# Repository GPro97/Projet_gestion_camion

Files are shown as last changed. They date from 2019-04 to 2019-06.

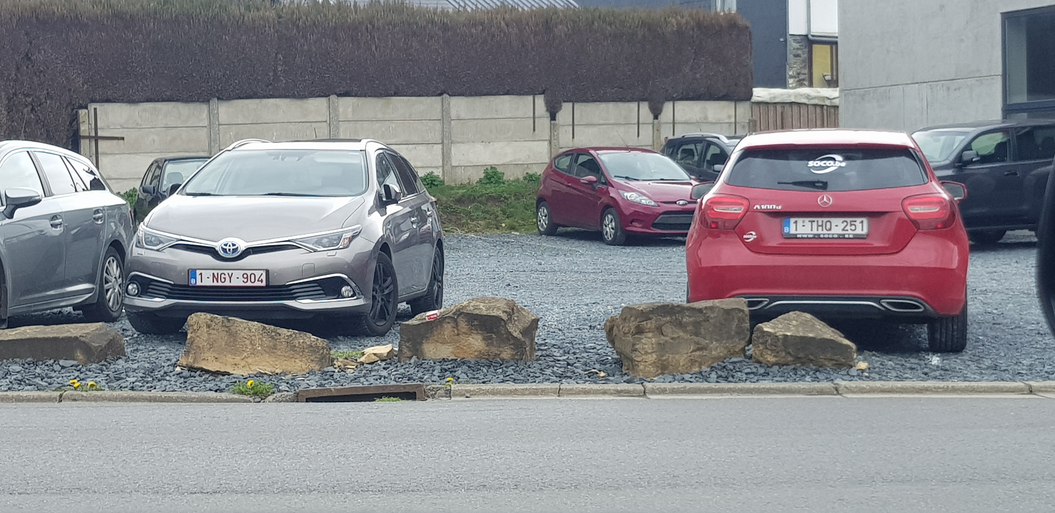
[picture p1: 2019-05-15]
images/test/img30.jpg

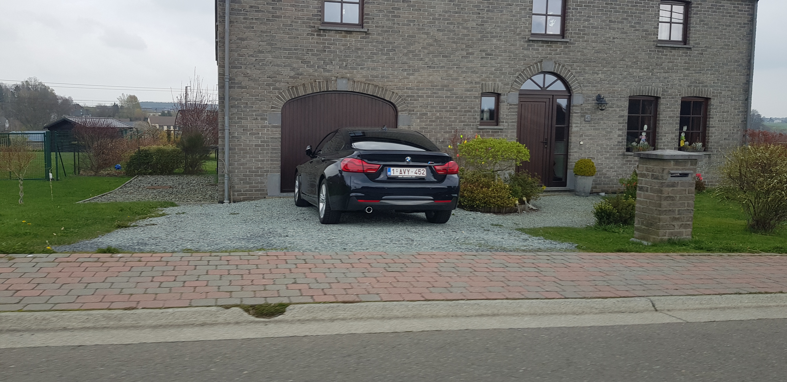
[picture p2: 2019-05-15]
images/test/img20.jpg

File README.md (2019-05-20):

# Projet_gestion_camion

## Utilisation
1. Raccorder l'alimentation du raspberry et raccorder les périphériques souvent: écran, clavier et souris
2. Vérifier que la caméra et l'écran LCD sont bien inséré dans les trous mis à disposition
3. Une fois le raspberry allumé, rendez-vous dans l'invite de commande et accédez au répertoire "tensorflow1/models/object_detection"
4. Activer le programme "python3 Object_detection_picamera_4.1.py"
5. Attendez 30 secondes pour le chargement jusqu'à ce que l'on voit à travers la caméra
6. Placez une plaque d'immatriculation devant et voyez le résultat

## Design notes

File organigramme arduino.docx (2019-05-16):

Vérifier qu’il n’y a plus de plaque et attendre en haut x secondes, puis modifié le message de l’écran

Allumage du LCD

On était l’écran, la led et on arrête les mouvements de la barrière

Démarrage programme et led pin 13 allumé

Est-ce qu’il y a une détection de plaque de plus de 1 secondes ?

Allumage du clignotement de la led rouge

Enclencher la montée de la barrière de 1 degré

Oui

Non

Est-t-elle arrivée en haut ?

Oui

Est-ce qu’on a attendu x secondes ?

Non

Enclencher la descente de la barrière de 1 degré

Oui

Est-t-elle arrivée en bas ?

Non

Oui

Non

Fin du setup

Allumage et initialisation du programme

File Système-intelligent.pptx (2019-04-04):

## Système intelligent

Reconnaissance de plaques d’immatriculation
Jérémy Denis et Geoffrey Kraus

## Description du projet

- Raspberry

- Arduino

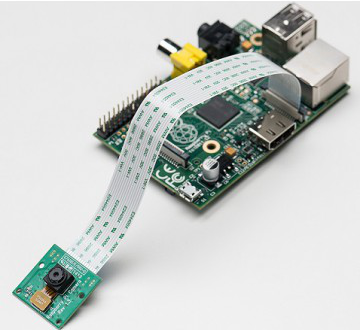
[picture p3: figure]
RÃ©sultat de recherche d'images pour "camera raspberry"

Communication

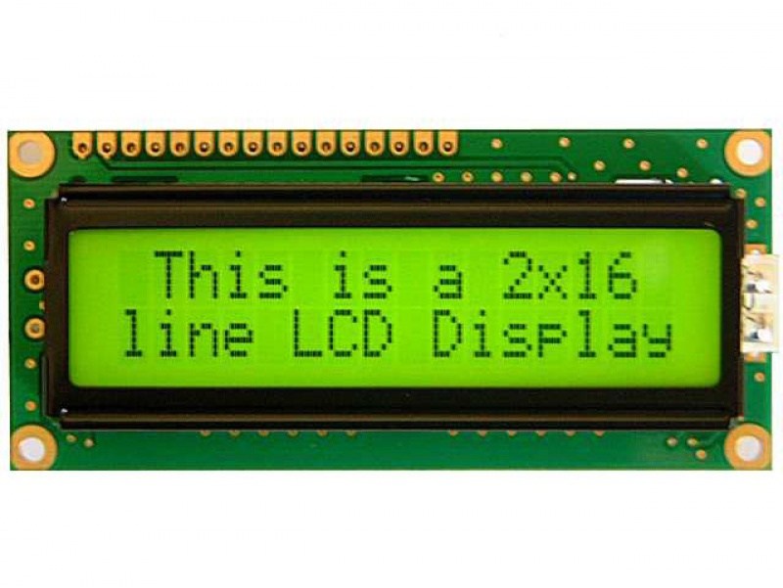
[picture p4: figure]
RÃ©sultat de recherche d'images pour "lcd"
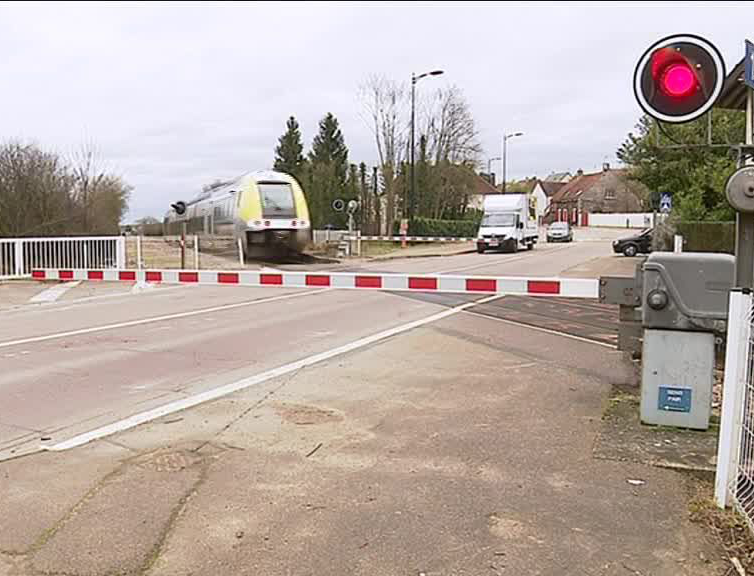
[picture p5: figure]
RÃ©sultat de recherche d'images pour "barriÃ¨re passage a niveau"
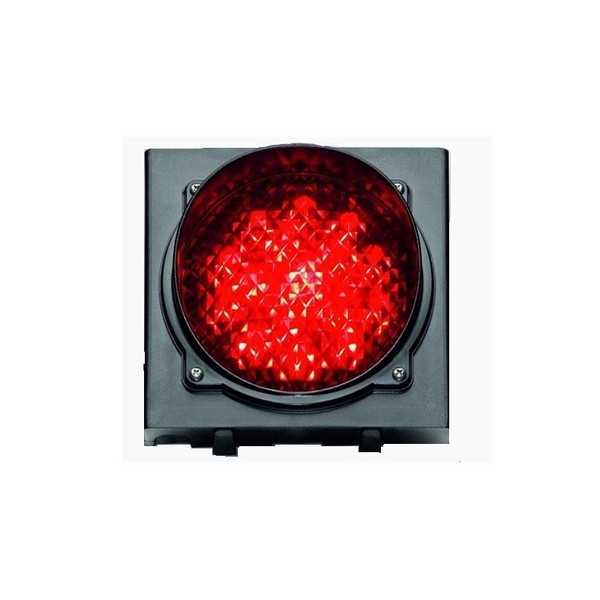
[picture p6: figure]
RÃ©sultat de recherche d'images pour "feu rouge"
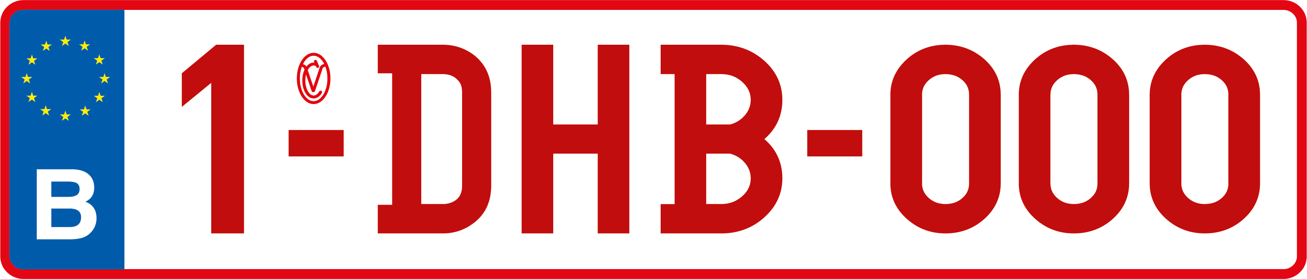
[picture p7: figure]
RÃ©sultat de recherche d'images pour "plaque d'immatriculation belge"

- Détection de plaques d’immatriculation belges

- Affichage de la plaque sur un LCD
- Gestion de l’ouverture d’une barrière lors de la détection d’une plaque
- Clignotement d’un feu lumineux lors de l’activation de la barrière

## Description du matériel nécessaire

Nous disposons de pratiquement tout le matériel nécessaire :
Arduino
LCD du kit Arduino
Raspberry Pi 3
Camera du kit Raspberry Pi 3
Led pour représenter le feu lumineux
Potentiomètre (kit Arduino) pour contrôler le clignotement de la LED
Servomoteur (kit Arduino) pour activer la barrière
Divers câbles et équipements esthétiques
Matériel manquant : barrière (imprimée en 3D ou maquette à fixer au servomoteur)

## Timeline et répartition des charges

Algorithme de reconnaissance plaque d’immatriculation

Programme de gestion de barrière et du LCD, suivi de la modélisation pratique de la barrière.

Modélisation des mises en places pratique du projet

Geoffrey

Jérémy

01/03 – 10/04

Geoffrey

47 days

Geoffrey
Jérémy

01/03 - 18/03

19/03 - 10/04

Communication entre Arduino et Raspberry

Réalisation pratique

Jérémy

10/04 – 25/04

23/04 - 03/05

Algorithme de reconnaissance des numéros écris sur la plaque

Pâques

Geoffrey

25/04 – 15/05

Feb

Mar

Apr

Mai

June

01/03/2019

15/05/2019

## Etat de l’art de l’existant

- Contrôle d’accès par lecture de plaques d’immatriculation (ALPR)
Ce système permet d’autoriser l’accès à un parking par lecture des plaques d’immatriculation. Il s’appuie sur une caméra IP associée à une carte Raspberry Pi et le logiciel de reconnaissance de plaques openALPR.
http://www.rgot.org/controle-dacces-par-lecture-de-plaques-dimmatriculation-alpr/
https://www.youtube.com/watch?v=sRnFKqWCVBM

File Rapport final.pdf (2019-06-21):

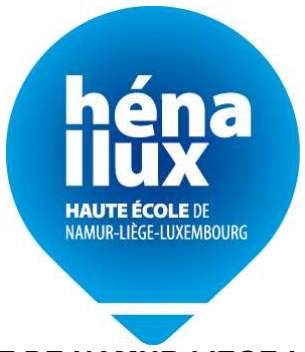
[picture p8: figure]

HAUTE ECOLE DE NAMUR-LIEGE-LUXEMBOURG

## DEPARTEMENT INGENIEUR INDUSTRIEL PIERRARD - VIRTON

### SYSTEMES INTELLIGENTS : RECONNAISSANCE D’UNE PLAQUE D’IMMATRICULATION ET CONTROLE D’UNE BARRIERE D’ENTREE

Professeurs : LIBERATORE C. et SLAMA R.

DENIS Jérémy
Année Académique | KRAUS Geoffrey
2018 – 2019 | M1A

2

## Table des matières

3

## Table des figures :

Figure 1.1 - Schéma d'illustration du projet | 4
Figure 4.1 - Schéma de câblage de l'arduino | 7
Figure 4.2 - Micro servomoteur [1] | 8
Figure 4.3 - Graphe temporel des impulsions PWM [2] | 8
Figure 4.4 - Structure du code arduino | 9
Figure 4.5 - Ordinogramme du code arduino | 10
Figure 4.6 - Barrière | 11
Figure 4.7 - Supports du servomoteur | 11
Figure 5.1 - Test de TensorFlow sur le Raspberry | 13
Figure 5.2 - Test de Protobuf sur le Raspberry | 15
Figure 5.3 - Premier test sur Raspberry | 16
Figure 5.4 - Exemple de photo prise pour l'entrainement | 17
Figure 5.5 - Logiciel LabelImg | 17
Figure 5.6 - Abandon du processus d'entrainement sur Raspberry | 20
Figure 5.7 - Fin de l'apprentissage du modèle sur Lubuntu | 20
Figure 5.8 - Modèle entrainé utilisé sur Lubuntu | 21
Figure 5.9 - Test final de la détection de plaque | 22
Figure 5.10 - Resultat final | Erreur ! Signet non défini.

## Table des tableaux :

Tableau 2.1 - Liste des composants du projet | 5

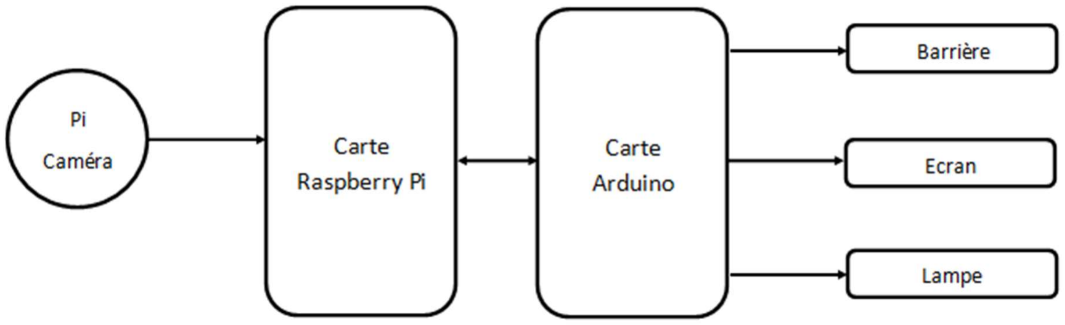
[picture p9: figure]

4

## 1. Introduction :

Dans le cadre du projet du cours de microcontrôleur et système intelligent, nous avons décidé de créer un système d’ouverture de barrière à la détection d’une plaque d’immatriculation d’un véhicule. Ce projet se divise donc en deux grandes parties : Raspberry et Arduino.
En effet, toute la partie commande de la barrière avec un écran et une lampe sera gérée par l’Arduino qui est un microcontrôleur. Et toute la partie reconnaissance de plaque est gérée par le Raspberry avec sa caméra pi.
Chaque partie sera réalisée séparément pour ensuite réaliser une communication entre les deux systèmes par le biais de un ou plusieurs câbles.

Figure 1.1 - Schéma d'illustration du projet

5

## 2. Tableau des composants

Tableau 2.1 - Liste des composants du projet
Dans le tableau 2-1, on retrouve tous les composants nécessaires au projet. En effet, on prenant la partie Arduino, on retrouve le microcontrôleur avec le LCD et le servomoteur ainsi deux potentiomètres. Un pour la luminosité du LCD et un pour une entrée analogique. Ensuite on retrouve la led rouge qui clignotera ainsi que les résistances pour protéger les potentiomètres et les leds.
Ensuite, on retrouve le raspberry avec la caméra, puis les différents fils de connections pour l’arduino ainsi qu’entre l’arduino et la raspberry. Et finalement, on retrouve le matériel nécessaire à la réalisation pratique.
En ce qui concerne l’impression 3D, on prend, ici, seulement le prix de la bobine en compte (soit 35 € du kg). Mais il faudrait également prendre en compte l’amortissement de la machine ainsi que sa consommation électrique. Données que nous ne possédons pas.
Arduino Uno | | 20,75 € | 1 | 20,75 € | Digi-Key | A000066 | [3] | Fourni par l'école
LCD | | 7,57 € | 1 | 7,57 € | Amazon | DLM-B00XOYIXI0 | [4] | Fourni par l'école
Servomoteur | | 4,75 € | 1 | 4,75 € | KAPshop | / | [5] | Fourni par l'école
Potentiomètre 10K | | 0,25 € | 2 | 0,50 € | Gotronic | 04601 | [6] | Fourni par l'école
Led rouge | | 0,15 € | 2 | 0,30 € | Gotronic | 03030 | [7] | Fourni par l'école

Résistance 220ohms
Pack de 10 | | 0,26 € | 1 | 0,26 € | RS Components | 135-500 | [8] | Fourni par l'école
Sous-total | 33,73 € Raspberry Pi 3 B+ | 63,70 € | 1 | 63,70 € | RS Components | 174-7510 | [9] | Fourni par l'école
Pi caméra V2 | | 23,09 € | 1 | | RS Components | 913-2664 | [10] | Fourni par l'école
Sous-total | 86,79 € Câble mâle-mâle | 2,41 € | 1 | 2,41 € | RS Components | 791-6463 | [11] | Fourni par l'école
Câble mâle-femelle | 2,41 € | 2 | 4,82 € | RS Components | 791-6454 | [12] | Fourni par l'école
Jumper Cable Kit Fil | 2,50 € | 1 | 2,50 € | Amazon | 14731 | [13] | Fourni par l'école
Sous-total | 7,32 € Bois | 20 € | / | / | Récupération | / | / | /
Impression 3D | | ( €/g ) | ( m ) | ( g ) | Nombre d'essai | Prix total
Barrière | 0,035 | 0,8 | 6 | 2 | 0,420 € | Fourni par l'école
Support haut du servo | 0,035 | 0,49 | 3 | 1 | 0,105 € | Fourni par l'école
Support bas du servo | 0,035 | 1,2 | 8 | 1 | 0,280 € | Fourni par l'école
Sous-total | 0,81 €
Total général | 128,65 € Raspberry Arduino Communication Montage pratique
Partie | Composants | Prix unit. | Qte | Prix tot. | Fournisseur | Réf site | Lien | Etat

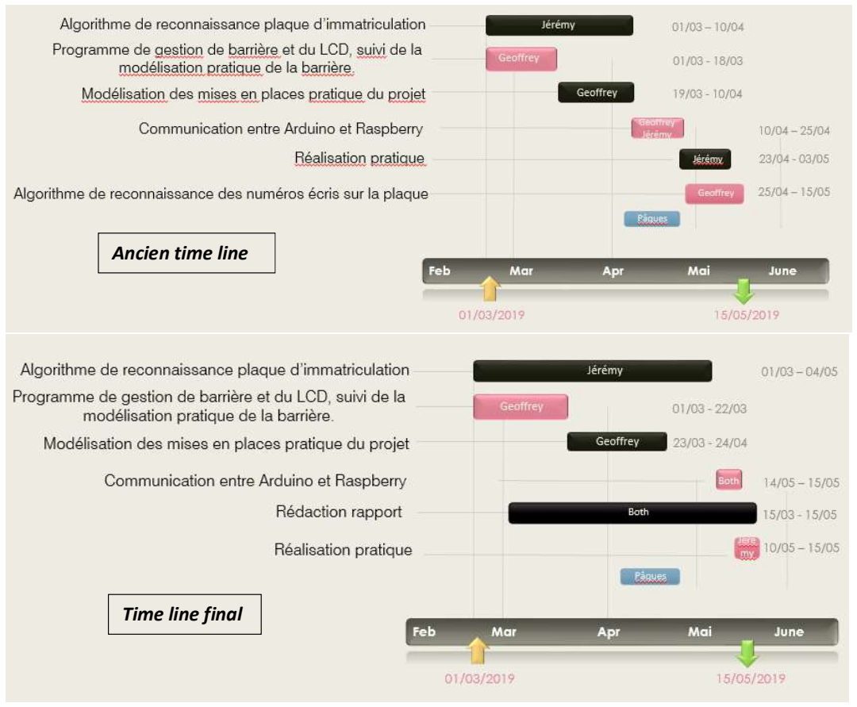
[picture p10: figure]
Ancien time line; Time line final

6

## 3. Time line final

Comme on peut remarquer, le time line a un peu bougé entre le début et la fin du projet. Et notamment parce que certaines tâches ont pris plus de temps qu’espéré. Nous avons également ajouté la partie « Rédaction du rapport » qui est tout de même une partie importante de ce projet. On peut également remarquer que la tâche « Algorithme de reconnaissance des numéros écris sur la plaque » ne fait plus partie du Time Line final. En effet, la reconnaissance de plaque est déjà très complexe, nous n’avons donc pas eu le temps nécessaire pour faire cet algorithme.

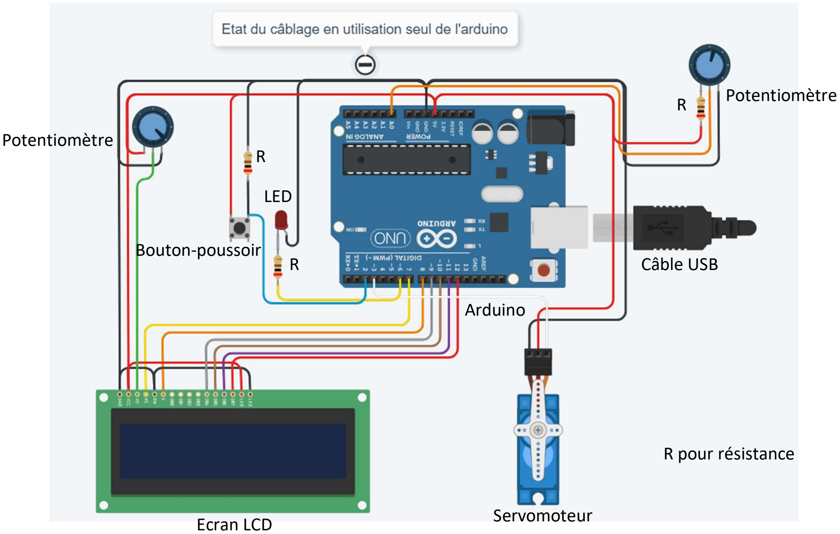
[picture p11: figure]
Ecran LCD; Servomoteur; Potentiomètre; Arduino; Bouton-poussoir; LED; R pour résistance; Câble USB

7

## 4. Partie 1 : Arduino

### 1. Composants :

Comme vu précédemment, le microcontrôleur Arduino va contrôler la barrière, l’écran et le clignotement d’une lampe. La barrière est réalisée avec un servomoteur, l’écran avec un LCD et lampe avec une led rouge.

Figure 4.1 - Schéma de câblage de l'arduino
Nous pouvons voir, sur cette figure 4.1, tout le circuit de la partie Arduino. Il faut prêter attention aux pins que l’on ne peut pas utiliser sur le microcontrôleur. Les pins 0 et 1 sont deux pins utilisées par le protocole RX et TX, utilisées comme communication série ainsi que pour l’écriture sur l’interface moniteur série. Ensuite c’est la pin 13 à laquelle il faut prêter attention car elle contrôle en même temps la petite LED « L » se trouvant sur le microcontrôleur. Etant donné que nous disposons d’assez de pin digital, nous utilisons cette LED pour s’assurer que le « void loop () » fonctionne bien. En bas à droit, nous retrouvons le servomoteur qui comporte 3 fils. Un noir pour la masse, un rouge pour l’alimentation 5 volts et un blanc/brun clair pour la commande. Cette commande se fait sur la pin 3 (PWM). En effet, pour commander le servomoteur, il faut lui envoyer des impulsions (d’où l’utilité d’une pin PWM) et c’est le temps de durée de pulsation qui déterminera l’angle que le servomoteur doit prendre (voir image 4.3). Une fois cet angle réglé, il s’efforcera au mieux possible de garder cette position jusqu’à la commande suivante.

8

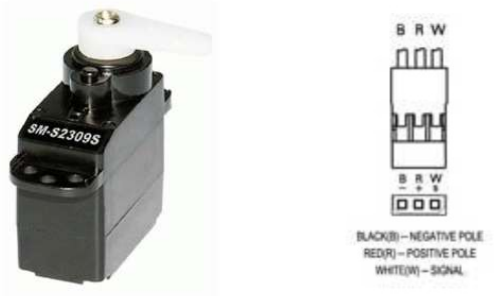
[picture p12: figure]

Figure 4.2 - Micro servomoteur [1]

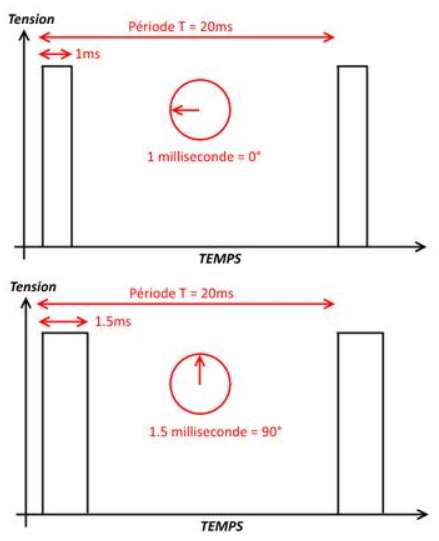
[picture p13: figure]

Figure 4.3 - Graphe temporel des impulsions PWM [2]
Ensuite, on retrouve l’écran LCD (liquid crystal display) dont le branchement peut rapidement devenir un casse-tête si l’on n’y met pas un peu de rigueur. On retrouve 2 fils d’alimentation 5 volts (rouge) et 3 fils de masse (noir). Les 6 autres pins sont reliés à l’Arduino sur les pins 7 à 12. 7 et 8 pour la communication et les 4 autres pour les données. Il y a aussi une pin (n°3 en vert) provenant d’un potentiomètre pour régler le contraste de l’écran.
Les trois derniers éléments sont plus simples. On retrouve un bouton poussoir simulant la communication avec le raspberry qui sera, bien entendu, remplacé par un fil de communication. Ensuite une LED rouge clignotant à une certaine fréquence lorsque la barrière est en mouvement ou en l’air, et finalement, un potentiomètre branché sur la pin analogique A0 qui fournira une fréquence comprise entre 1 et 6 Hz pour le clignotement de la LED.

9

### 2. Programme :

La structure même du code de l’arduino est très simple.

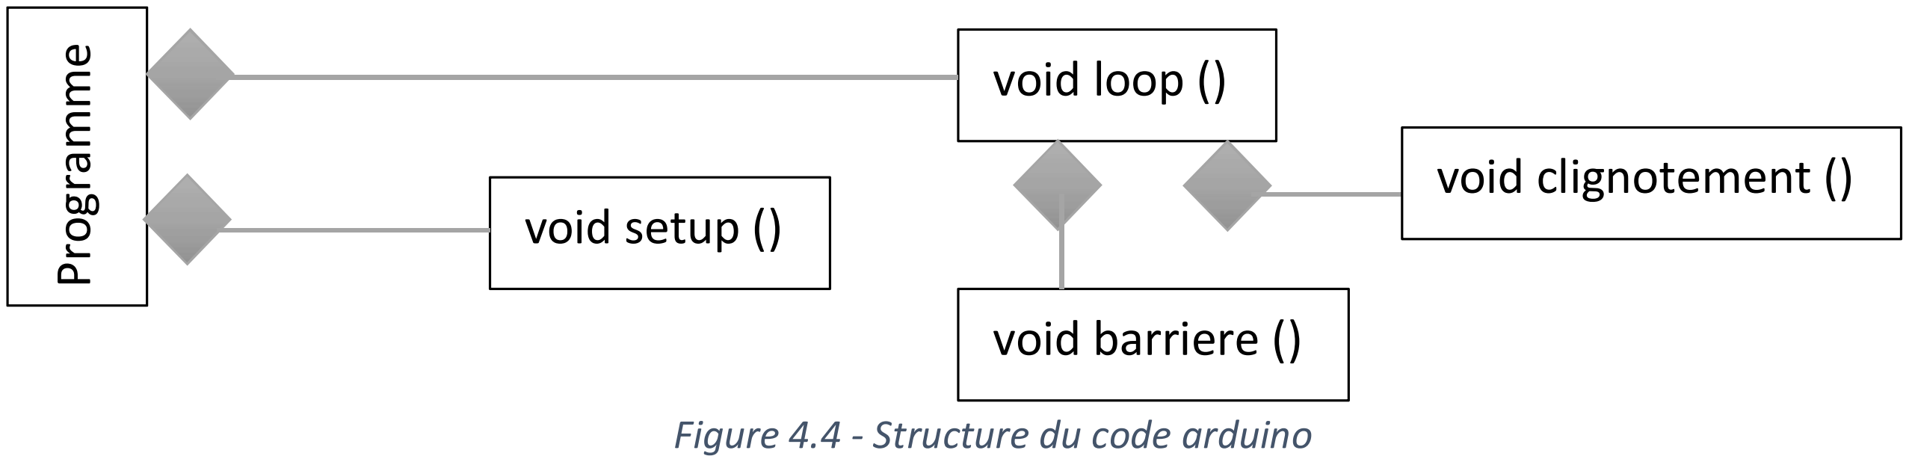
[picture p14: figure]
void setup (); void clignotement (); void barriere (); Figure 4.4 - Structure du code arduino

En regardant ce diagramme, on peut facilement comprendre que le programme fait appel au setup et au loop, et le loop fait lui-même appel au sous-programme du clignotement de la LED et au sous-programme du mouvement de la barrière.
Un peu plus loin, on retrouve un ordinogramme (figure 4.5) qui permet de comprendre facilement comment il tourne mais il n’est pas fort complet. En fait, avant même le void setup, on retrouve l’insertion des bibliothèques nécessaires (pour le servomoteur ainsi que pour l’écran LCD) suivi ensuite de toutes les déclarations de variables bool, int et float (pour les temporisations) et les déclarations de numéro de pin. Pour terminer, on déclare le nom du servomoteur et les 6 pins utiles à l’écran.
Ensuite vient le void setup () dans lequel on définit chaque pin en entrée ou sortie, puis on attache un pin au servomoteur et on le positionne. Et pour finir on paramètre la taille du LCD avant d’attendre pour une durée de 2 secondes. Ce temps d’attente n’est pas une obligation mais il permet de s’assurer que les mouvements engendrés par le void setup soient bien terminé.
Et enfin vient le void loop qui, on le rappel, est l’endroit dans lequel le programme va tourner en permanence. Dans celui-ci, on va tout d’abord aller lire la valeur de l’entrée analogique provenant du potentiomètre et la convertir grâce à un tableau en fréquence de 1 à 6 Hz. Ensuite, cette fréquence va donner un temps entre chaque clignotement de la LED. Avant d’utiliser les sous-programmes, il nous manque encore la communication avec le raspberry. On lit la valeur et on vérifie qu’elle reste actif plus d’une seconde pour éliminer les petites imperfections que pourrait engendrer la reconnaissance de plaque.
Grâce à cette vérification, nous pouvons enfin accéder aux deux sous-programmes dont le premier est le clignotement de la LED. Dans celui-ci, on vérifie le temps d’écoulement depuis le dernier changement d’état de la LED. Si celui-ci est supérieur ou égal à ce que l’on souhaite (c’est-à-dire le temps induit par la fréquence), alors on lit l’état actuel de la LED et on l’inverse. De cette manière, on crée un clignotement.
Le sous-programme suivant (c’est-à-dire le mouvement de la barrière) écrit dans un premier temps sur l’écran LCD et se divise ensuite en 4 parties conditionnelles :
- La première vérifie que la barrière n’a pas encore bougé et la fait monter de 1 degré jusqu’à un angle de 89°.
- La deuxième vérifie que la barrière est bien en haut et qu’il n’y a plus de plaque détectée. Ensuite, elle attend 2 secondes.
- La troisième vérifie que la barrière est toujours en haut qu’elle a bien attendu pour la faire

# redescendre à l’horizontal. Programme void loop ()

10

- Et enfin, la dernière vérifie que toutes les autres actions ont bien été effectuées pour arrêter le clignotement, effacer l’écran et permettre le réarmement du futur mouvement. Le code a été programmé de façon à ne jamais rester bloqué à un endroit. Dans le cas où la barrière est monté de 1 degré, le programme fait d’abord tout le tour des autres conditions avant de revenir à celle de la monté de la barrière.

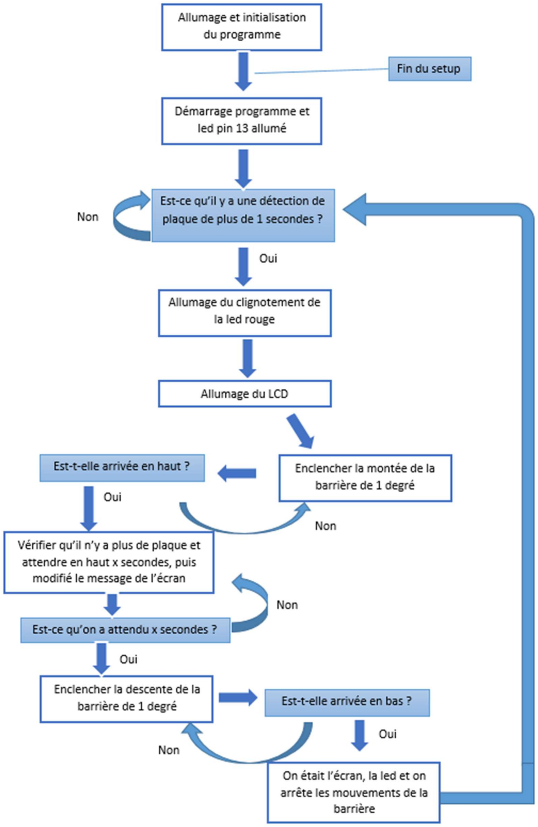
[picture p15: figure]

Figure 4.5 - Ordinogramme du code arduino

11

Bien entendu, ce genre de programme ne s’écrit pas en une seule fois et nécessite des tests et du temps. Par exemple, les premières ébauches de code ne ressemblaient pas à celle que nous avons maintenant. On peut notamment voir les tests du servomoteur à partir du commit suivant : https://github.com/GPro97/Projet_gestion_camion/commit/5b1bba8dc9cf58819158919282b81bce4 895565b
Ensuite est seulement venu le contrôle de vitesse du servo fourni par le commit suivant : https://github.com/GPro97/Projet_gestion_camion/commit/5b1bba8dc9cf58819158919282b81bce4 895565b
Tout cela pour en arriver à un programme final, complet et sans erreur.

### 3. Modélisation 3D

Pour donner un peu plus de réalisme au projet, 3 dessins ont été réalisés puis imprimés avec une imprimante 3D pour créer un support au servomoteur (Figure 4.7) et une barrière à lui fixer (Figure 4.6).

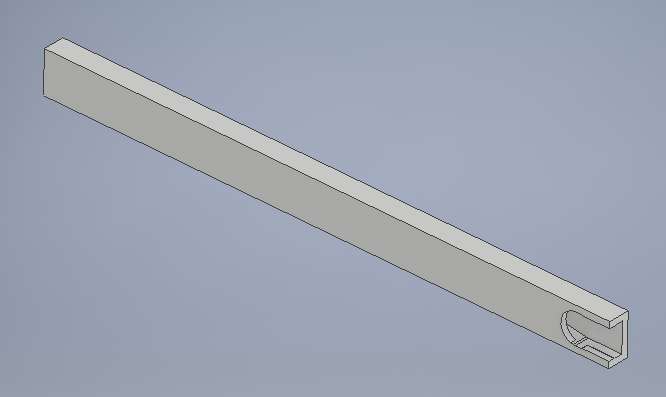
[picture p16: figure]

Figure 4.6 - Barrière

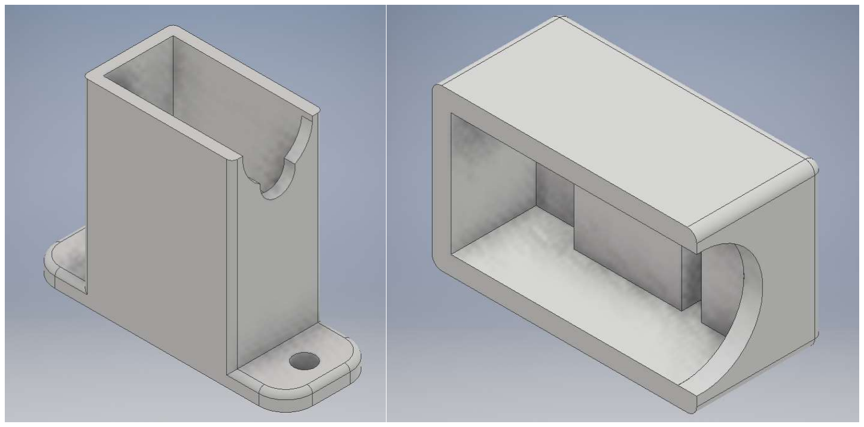
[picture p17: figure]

Figure 4.7 - Supports du servomoteur
A partir du commit suivant, vous pouvez accéder aux fichiers du projet et des dessins : https://github.com/GPro97/Projet_gestion_camion/commit/5b1bba8dc9cf58819158919282b81bce4 895565b

12

## 5. Partie Raspberry (reconnaissance)

Notre projet vise à détecter les plaques d’immatriculations. Nous avons donc rejeté l’idée du traitement d’images car cela ne convient pas spécialement pour cette tâche. C’est principalement utilisé pour les couleurs, les textures, etc. Nous sommes donc partis sur du Deep Learning. L’apprentissage profond (Deep Learning) fait partie d’une famille de méthodes d'apprentissage automatique fondées sur l’apprentissage de modèles de données. Une observation (une image) peut être représentée de différentes façons par un vecteur de données, notamment en fonction de :
- L’intensité des pixels dont elle est constituée ;
- Ses différentes arêtes ;
- Ses différentes régions, aux formes particulières.
Cette méthode est idéale car on cherche une région dans l’image qui est la plaque d’immatriculation.
Notre cas d’utilisation spécifique est la détection d’objets. On peut donc utiliser le deep learning à différents niveaux :
Niveau 1 : Utilisez un modèle pré-entraîné et l’appliquez directement sur nos données pour reconnaître les plaques. Cette méthode est la moins complexe et la plus rapide car nous n’avons pas besoin de construire ou d’entraîner un modèle.
Niveau 2 : Entraîner un modèle sur nos propres données, afin que le modèle puisse apprendre et reconnaître précisément un objet. Ce niveau nécessite d’entraîner un modèle sur les données que nous avez labellisées au préalable. Cela prend plus de temps mais apporte des résultats plus pertinents car le modèle reconnaîtra les références exactes des objets choisis.
Niveau 3 : Créez notre propre modèle à partir de zéro. Dans ce niveau, nous n’entraînons pas seulement un modèle, nous le construisons dès le début. Il peut s’agir de l’ajustement de paramètres sur un modèle existant, ainsi que du développement d’une nouvelle architecture de réseau neuronaux. Ce niveau est plus dédié à la recherche, car il s’agit d’une approche qui prend beaucoup de temps. Dans le cadre du cours, nous allons donc partir sur le deuxième niveau.

### 1. Installation de TensorFlow

En premier lieu, on met à jour notre Raspberry pi. Cela est vivement conseillé avant de travailler avec divers programmes. On a alors lancé ces lignes de commandes suivantes :
sudo apt-get update
sudo apt-get dist-upgrade
Maintenant que le Raspberry est à jour, nous allons commencer par installer le logiciel de machine Learning TensorFlow.
https://www.tensorflow.org/
TensorFlow est une bibliothèque de logiciels open source pour le calcul numérique à l'aide de graphiques de flux de données. Il a été développé à l'origine par Google Brain Team au sein de l'organisation de recherche Machine Intelligence de Google pour l'apprentissage par la machine et la

13

recherche sur les réseaux neuronaux profonds, mais le système est suffisamment général pour pouvoir s'appliquer à une grande variété d'autres domaines également.
TensorFlow est multiplateforme. Il fonctionne sur presque tout : les processeurs graphiques et les processeurs, y compris les plates-formes mobiles et intégrées, et même les unités de traitement de tenseurs (TPU), qui sont du matériel spécialisé permettant d'effectuer des calculs de tenseurs. https://github.com/lhelontra/tensorflow-on-arm/releases/download/v1.13.1/tensorflow-1.13.1-cp35-none-linux_armv7l.whl
TensorFlow a aussi besoin d’une librairie LibAtlas pour fonctionner. Pour l’installer, on peut lancer les commandes suivantes :
sudo apt-get install libatlas-base-dev
sudo pip3 install pillow lxml jupyter matplotlib cython
sudo apt-get install python-tk
Maintenant, on peut lancer l’installation de TensorFlow
sudo pip3 install « chemin du fichier whl TensorFlow »
Ayant la version 3.5.3 de python, nous avons pu remarquer que la version 1.13.1 de TensorFlow n’était pas compatible. Il a donc fallu supprimer cette version de TensorFlow. Divers forums ont confirmé ce résultat. A noter que changer la version de python3 déjà installé dans le raspberry n’aurais rien changé car les versions 3.6 sont instables et les versions 3.7 ne prennent pas encore en charge TensorFlow.
Par la suite nous avons installé une version plus ancienne. https://github.com/lhelontra/tensorflow-on-arm/releases/download/v1.8.0/tensorflow-1.8.0-cp35-none-linux_armv7l.whl
En désinstallant TensorFlow 1.13.1 et en installant l’ancienne version 1.8.0, nous avons subi bons nombres de problèmes de compatibilité de certaines dépendances encore présente de la version
1.13.1. Par question de facilité, nous avons donc réinitialisé le Raspberry. Nous en avons profité pour installer Raspbian Strech sur une carte SD de plus grande capacité (16Gb).
Après avoir réinstallé la version 1.8.0. Nous l’avons testé dans un script python3. On peut voir que la fonction import fonctionne (voir figure 5.1), ce qui indique que TensorFlow est bien installé.

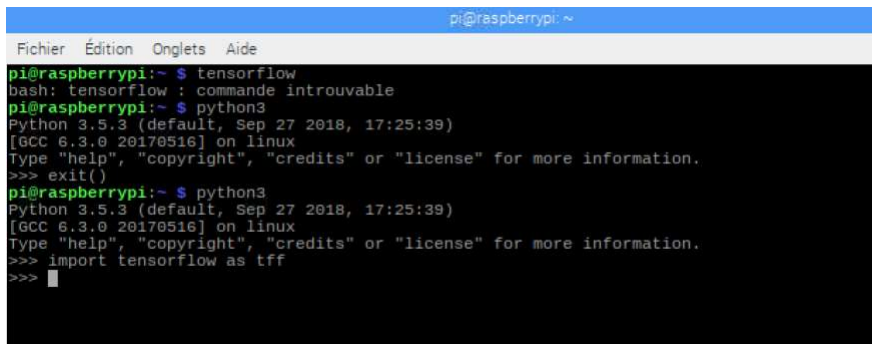
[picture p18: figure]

Figure 5.1 - Test de TensorFlow sur le Raspberry

14

### 2. Installation d’OpenCV

Maintenant que le TensorFlow est installé, il faut installer une bibliothèque graphique spécialisé dans le traitement d'images en temps réel. Nous allons utiliser OpenCV, c'est la bibliothèque de référence pour la vision par ordinateur.
https://opencv.org/
OpenCV (Open Source Computer Vision) est une bibliothèque proposant un ensemble de plus de 2500 algorithmes de vision par ordinateur, accessibles au travers d'API pour les langages C, C++, et Python. Elle est distribuée pour les plateformes Windows, GNU/Linux, Android et MacOS. Initialement écrite en C il y a 10 ans par des chercheurs de la société Intel, OpenCV est aujourd'hui développée, maintenue, documentée et utilisée par une communauté de plus de 40 000 membres actifs.
Avant de l’installer, nous avons besoin de différentes dépendances.
sudo apt-get install libjpeg-dev libtiff5-dev libjasper-dev libpng12-dev
sudo apt-get install libavcodec-dev libavformat-dev libswscale-dev libv4l-dev sudo apt-get install libxvidcore-dev libx264-dev
sudo apt-get install qt4-dev-tools

Maintenant, nous pouvons installer OpenCV :

pip3 install opencv-python

### 3. Installation de Protobuf

L’API (application programming interface) de détection d’objets TensorFlow utilise Protobuf, un package qui implémente le format de données. Protocol Buffers est un format de sérialisation avec un langage de description d'interface développé par Google. L'implémentation d'origine publiée par Google pour C++, Java et Python est disponible sous une licence libre. Malheureusement, il n’existe actuellement aucun moyen facile d’installer Protobuf sur le Raspberry Pi. Nous devons le compiler nous-mêmes à partir des sources, puis l’installer.
En premier lieu, on installe les packages pour compiler Protobuf :
sudo apt-get install autoconf automake libtool curl
Ensuite, on le télécharge de la source :
wget https://github.com/google/protobuf/releases/download/v3.5.1/protobuf-all-3.5.1.tar.gz On entre ensuite dans la directory pour exécuter divers commandes :
./configure
make check
sudo make install
cd python
export LD_LIBRARY_PATH=../src/.libs

15

python3 setup.py build --cpp_implementation python3 setup.py test --cpp_implementation
sudo python3 setup.py install --cpp_implementation
export PROTOCOL_BUFFERS_PYTHON_IMPLEMENTATION=cpp export PROTOCOL_BUFFERS_PYTHON_IMPLEMENTATION_VERSION=3
sudo ldconfig
Avec la faible puissance du processeur du Raspberry, il aura fallu approximativement 3 heures pour exécuter toutes les commandes. Pour vérifier que Protobuf est bien installé, il suffit de vérifier si la commande protoc nous amène bien l’aide. Cela est le cas, nous pouvons passer à la nouvelle étape.

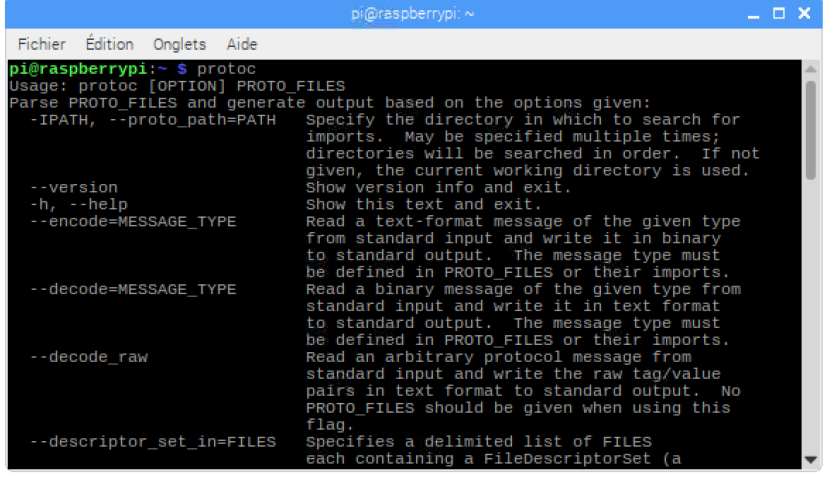
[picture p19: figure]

Figure 5.2 - Test de Protobuf sur le Raspberry

### 4. Installation des modèles TensorFlow

Vu que nous allons entrainer un modèle à partir d’un qui est déjà existant, il va nous falloir télécharger les différents modèles TensorFlow
https://github.com/tensorflow/models.git
La partie qui nous intéresse est l’« Object_détection ».

### 5. PYTHONPATH

Ensuite, nous devons modifier le PYTHONPATH. Le pythonpath indique à python quels dossiers il doit prendre en compte pour sa recherche de modules. Il va devoir pointer sur certains répertoires de TensorFlow que nous venons de télécharger. Nous allons donc modifier le fichier ~/.bashrc pour que PYTHONPATH soit défini chaque fois que nous ouvrons un terminal. On y ajoute donc simplement: export
PYTHONPATH=$PYTHONPATH:/home/pi/tensorflow1/models/research:/home/pi/tensorflow1/mode ls/research/slim
A noter que sur le Raspberry, notre dossier models se trouve dans un répertoire préalablement créé tensorflow1.

### 6. Premier test de reconnaissance :

Maintenant nous allons télécharger un programme .py qui va utiliser la Picamera (ou une caméra usb) ainsi qu’un modèle pour nous permettre de réaliser de la reconnaissance d’objet.

16

https://github.com/GPro97/Projet_gestion_camion/commit/9bae59446e5cc9bba70614b4980a79f71 368cdca
Comme on peut le voir à la ligne 55, ce programme utilise le modèle ssd_mobilenet_v2_coco_2018_03_29 Il va donc falloir le télécharger. http://download.tensorflow.org/models/object_detection/ssd_mobilenet_v2_coco_2018_03_29.tar. gz
Une fois extrait et placé dans le même directory, on peut tester le programme.

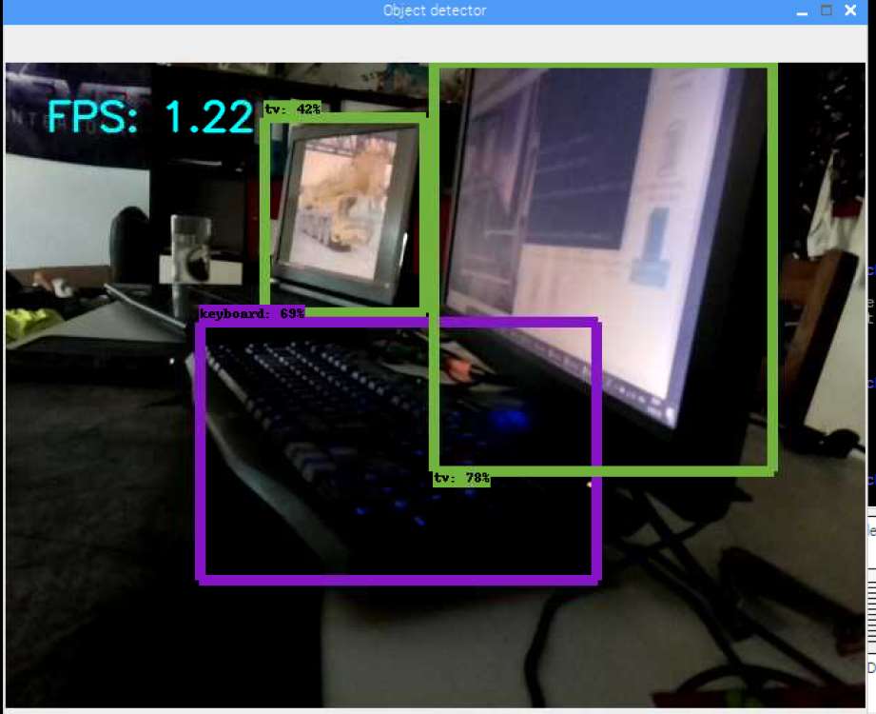
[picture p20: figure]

Figure 5.3 - Premier test sur Raspberry
On s’aperçoit que le programme met environ 30 secondes pour se lancer. Le temps de charger le modèle ainsi que les autres dépendances. Il fonctionne correctement avec néanmoins une grande latence. Nous tournons aux alentours de 1.2 images par seconde. Un second test a été réalisé en diminuant la qualité de la caméra à 480p (720p lors du premier test) mais cela n’a rien changé au niveau des images par seconde. Une hypothèse a été émise : Le processeur du Raspberry n’est pas assez puissant et donc n’a pas le temps de scanner l’image à trop haute vitesse.
Maintenant que tout est en place, nous allons nous attaquer à la grosse partie de ce projet, entrainer un modèle pour qu’il nous permettre de détecter les plaques d’immatriculation qui passeront devant la Picamera.
Nous allons procéder par différentes étapes :
- Collecte d’images contenant des plaques d’immatriculation
- Transformer les photos .jpeg en fichiers .xml
- Transformer les fichiers .xml en .csv
- Transformer les fichiers .csv en .TFRecord
- Entrainer notre modèle

### 7. Collecte de photos

Pour entrainer notre modèle nous allons devoir collecter une série de photos de véhicules en situations réelles de véhicule où l’on peut voir la plaque d’immatriculation. (Voir figure 5.4)

17

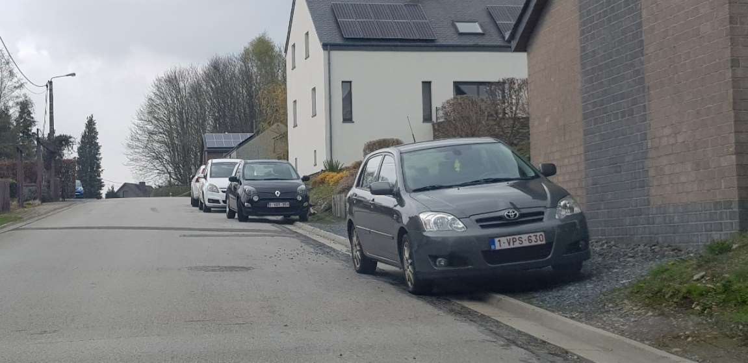
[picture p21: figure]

Figure 5.4 - Exemple de photo prise pour l'entrainement
Pour un entrainement correct, il faut au minimum 100 images par classe (objet à détecter) mais idéalement 500 images ou plus encore. Pour notre projet nous avons utilisé 60 photos.
NB : Les photos ont été prises en 4k (4 096 × 2 160) ce qui donne 8 847 360 pixels. Durant l’entrainement plus tard, nous avons observé que chaque étape prenait 120 secondes ce qui est beaucoup trop important vu le grand nombre à réaliser. Nous avons donc diminué la qualité à 480p (1280 x 720) ce qui donne 921 600 pixels soit 10 fois moins.

### 8. LabelImg

Toutes nos photos sont prêtes. Nous allons devoir nous attaquer au programme LabelImg https://github.com/tzutalin/labelImg.git
Ce programme nous permet de dessiner des encadrements de façon aisée autour des éléments qui nous intéressent. On peut appeler les encadrements comme on le souhaite pour différentes catégories d’objet par exemple (dans notre cas on a un seul type nommé « licenceplate »). Par la suite, LabelMap créé un fichier .xml du même nom que le fichier .jpg auquel il se rapporte.

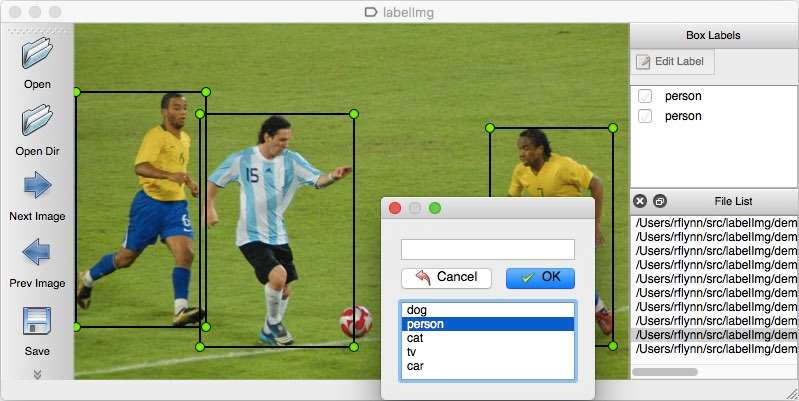
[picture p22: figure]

Figure 5.5 - Logiciel LabelImg
Dans ce fichier .xml, on retrouve différents éléments :
- La taille de l’image
- Le fichier .jpg auquel il se rapporte
- Le nom de la catégorie de chaque encadrement
- Les positions (xmin,ymin et xmax,ymax) de chaque encadrement

18

Une fois que tous les fichiers .xml sont réalisés, on va les séparer en 2 fichiers. Un fichier « train » qui comportera 90% des images et de leur fichier .xml associé. Et le second « test » comportera le reste (10%).

### 9. Conversion du format .xml en .csv

Pour pouvoir créer nos fichiers TFRecord, il faut d’abord passer sous un format .csv.
Un fichier CSV est un fichier texte, par opposition aux formats dits « binaires ». Chaque ligne du texte correspond à une ligne du tableau et les virgules correspondent aux séparations entre les colonnes. Les portions de texte séparées par une virgule correspondent ainsi aux contenus des cellules du tableau.
Il existe un programme xml_to_csv.py prévu à cet effet : https://github.com/datitran/raccoon_dataset/blob/master/xml_to_csv.py
Il faut appliquer quelques changements pour pointer dans les bons dossiers. https://github.com/GPro97/Projet_gestion_camion/commit/fed5f08fe0103ca523ff79ec0fe85702b3f 18821
Ensuite on peut exécuter le fichier : python3 xml_to_csv.py
On obtient:
https://github.com/GPro97/Projet_gestion_camion/commit/393379d2bd82f0926299fc8610a063c29 37966a0

### 10. Conversion du format .csv en .TFRecord

Comme le point précédent un programme est prévu à cet effet (generate_tfrecord). La seule modification à faire se trouve au niveau des classes à détecter. https://github.com/GPro97/Projet_gestion_camion/commit/4888c238af3a3033873ac5db94b4647dc 66e9b84
Un format TFRecord stock les données en une chaine de binaire. Cela facilite l’utilisation des données car un programme gère beaucoup mieux une suite d’informations binaires que de changer de fichier à chaque fois.
On peut l’exécuter de la manière suivante :
python3 generate_tfrecord.py --csv_input=data/train_labels.csv --output_path=data/train.record --image_dir=images/
python3 generate_tfrecord.py --csv_input=data/test_labels.csv --output_path=data/test.record --image_dir=images/
Voici les résultats :
https://github.com/GPro97/Projet_gestion_camion/commit/f64c59f585ad08c738fd5c9e7b408bd0d acf36e2
Le train.record ne se trouve pas sur GitHub car il fait 105Mo ce qui dépasse la limite autorisé par git.

19

### 11. Fichier de configuration du modèle :

Maintenant il nous reste à paramétrer le fichier de configuration du modèle que nous allons entrainer. Pour l’entrainement, nous nous baserons sur le modèle utilisé lors du premier essai (ssd_mobilenet_v2_coco_2018_03_29).
On crée un répertoire « training » se trouvant dans le même dossier que le modèle. Dans celui-ci, on y ajoute le fichier de configuration présent dans le fichier du modèle. De base, il est appelé pipeline.config mais par facilité il sera renommé : ssd_mobilenet_v2_coco_2018_03_29.config
Il y a quelques éléments à codifier, des annotations sont présente sur le git. https://github.com/GPro97/Projet_gestion_camion/commit/07b22c779fdd414eeb8ca3cbc6fa2cf96e a5e328
NB : on peut voir que le nombre d’images utilisés ainsi que le nombre d’étapes pour l’entrainement ne sont pas cohérent avec les valeurs de base. Cela signifiera que notre modèle sera moins bon que le modèle sur lequel on se base.
Dans le dossier training, il nous reste à ajouter un fichier object-detection.pbtxt
Celui-ci indique quelle id correspond à quel objet. Dans notre cas, c’est très simple car nous n’avons que « licenceplate » qui prendra l’id 1.

### 12. Entrainement du modèle :

Il est maintenant temps d’entrainer le modèle. Pour ce faire il y a un programme train.py prévu à cet effet. De base il se trouve dans l’onglet legacy mais par facilité, on le déplace au même niveau que training et que le modèle (ssd_mobilenet_v2_coco_2018_03_29).
python3 train.py --logtostderr --train_dir=training/ --pipeline_config_path=training/ ssd_mobilenet_v2_coco_2018_03_29.config
Ici, le Raspberry commence l’entrainement. Cependant à partir de quelques étapes d’apprentissage ou avant, le Raspberry plante ou abandonne le processus. Cela est due au manque de mémoire (erreur : « std: :bad_alloc ») et à la puissance du processeur. Après plusieurs essais, nous retrouvons toujours le même diagnostic.

20

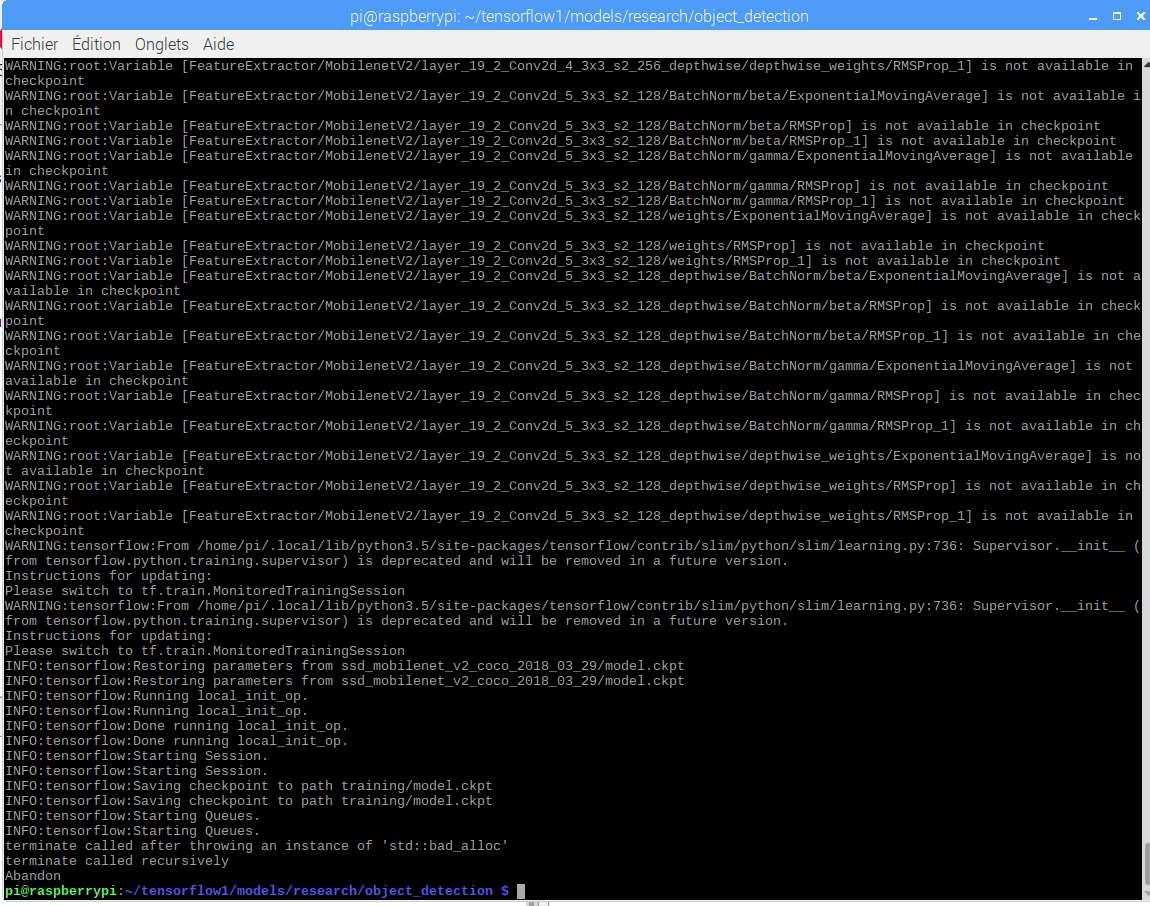
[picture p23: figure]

Figure 5.6 - Abandon du processus d'entrainement sur Raspberry
Pour pouvoir contourner le problème, nous avons décidé de réaliser l’entrainement sur un ordi possédant Lubuntu (une version allégée d’Ubuntu) comme système d’exploitation. Nous avons donc effectué les mêmes étapes que vu précédemment mais sur l’ordinateur. Nous avons lancé l’entrainement et après environ 20 heures, l’apprentissage c’est terminé correctement comme on peut le voir ci-dessous.

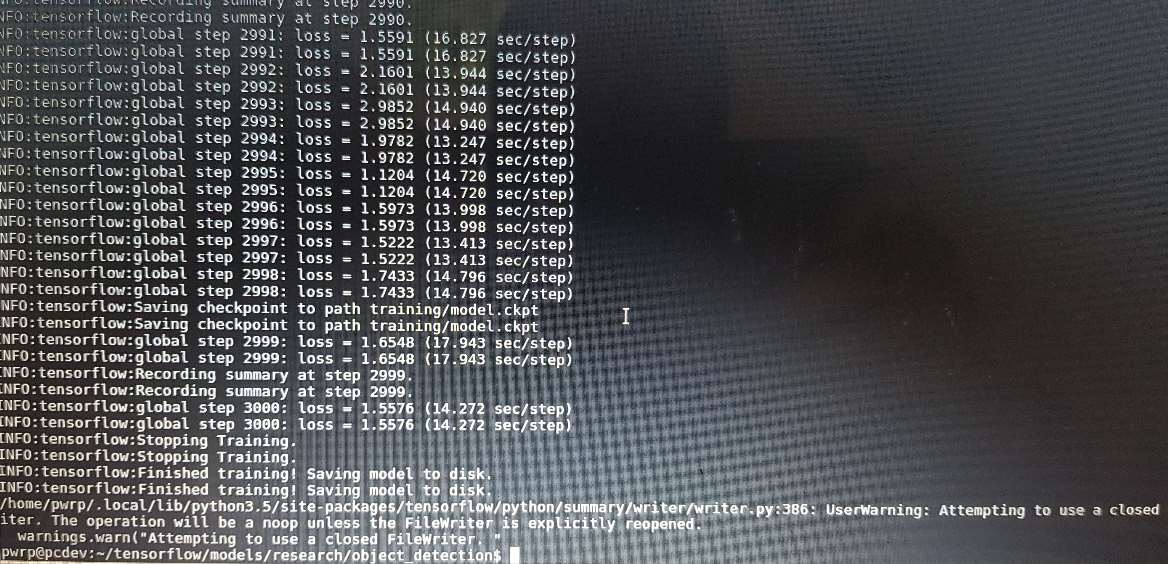
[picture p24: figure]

Figure 5.7 - Fin de l'apprentissage du modèle sur Lubuntu
On peut voir que le train.py c’est bien arrêté à la 3000ème itération.
L’entrainement terminé, on aperçoit différents éléments ajoutés dans le dossier training. Ils seront utilisés juste après.

21

Pour obtenir notre modèle final, il ne reste plus qu’à utiliser le programme export_inference_graph.py :
python3 export_inference_graph.py \
--input_type image_tensor \
--pipeline_config_path training/ssd_mobilenet_v1_pets.config \ #directory du fichier de config --trained_checkpoint_prefix training/model.ckpt-3000 \ #cela dépend du nombre d’étape réalisé --output_directory licenceplate_inference_graph #nom du modèle créé

Le modèle ne se trouve pas sur GitHub car il est trop volumineux.

On peut maintenant modifier le programme utilisant la Picamera pour y ajouter le nouveau modèle. On obtient:

https://github.com/GPro97/Projet_gestion_camion/commit/9022c1c2871b559961292d36e81eb9dcf 0279930

En testant le programme sur Raspberry, pour une raison inconnue, il ne démarre pas. Pour vérifier le bon fonctionnement du modèle, nous avons décidé de l’essayer sur l’ordinateur. On peut voir le résultat ci-dessous :

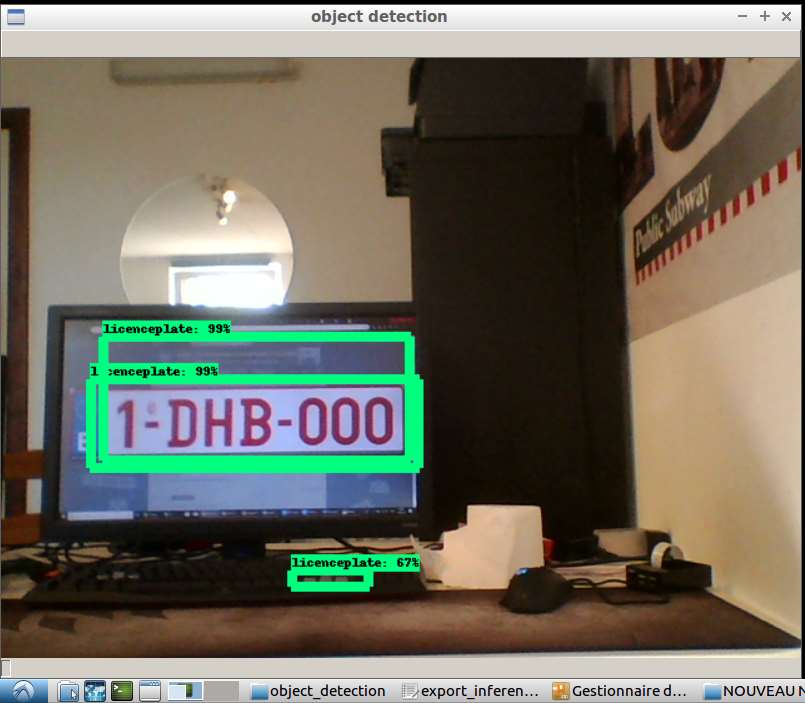
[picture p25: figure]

Figure 5.8 - Modèle entrainé utilisé sur Lubuntu
Le programme fonctionne mais il a du mal à détecter les plaques quand l’image couvre des surfaces carrées comme un écran ou autres. Cela dit nous considérons qu’il est fonctionnel car il dysfonctionne peu lorsque la plaque se situe sur un véhicule à l’extérieur.

22

Pour mener à bien notre projet sur Raspberry, vu que notre modèle est fonctionnel mais n’est pas compatible sur Raspberry, nous avons décidé de partir sur un modèle détectant les plaques se trouvant sur GitHub.
https://github.com/GPro97/Projet_gestion_camion/commit/e12c5ea732a488a98f68a8f201118f8cea bb9824
Nous avons remodifié notre programme utilisant la Picamera. De plus, nous avons ajouté quelques modifications du programme. Quand une plaque (ou plus) est détectée, un bit se met à 1. L’Arduino pourra alors lire le bit pour lever la barrière. https://github.com/GPro97/Projet_gestion_camion/commit/44e014954b1d14c477c2a74f9651eca66 ffbde9e

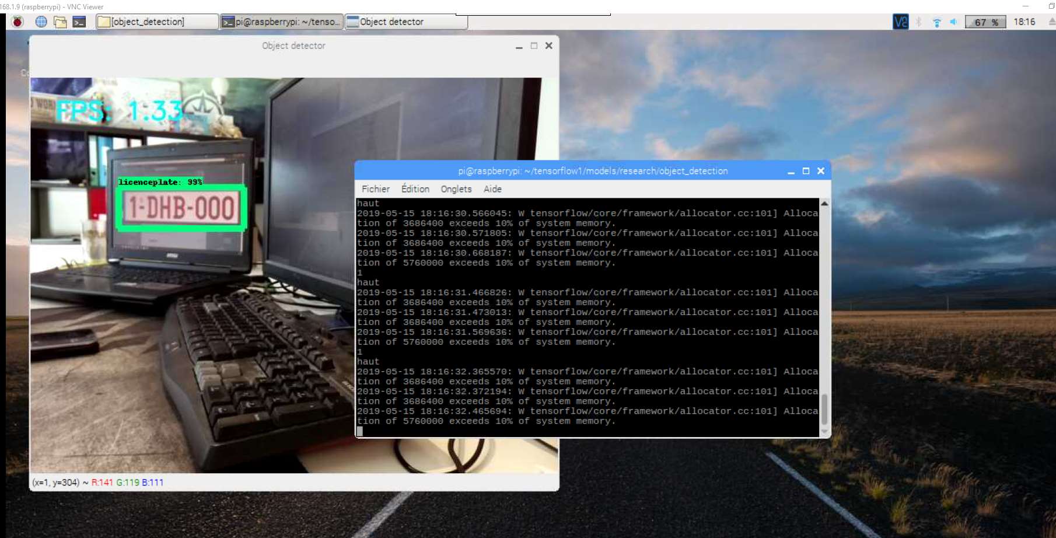
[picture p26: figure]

Figure 5.9 - Test final de la détection de plaque
Le système fonctionne maintenant correctement. Le bit se met bien à 1 quand on détecte la plaque et les plaques sont détectées correctement. Cela met fin à notre projet de reconnaissance de plaque d’immatriculation.


Figure 5.10 - Résultat final

23

## 6. Conclusion :

Nous avons pu constater que le DEEP LEARNING est quelque chose d’extrêmement complexe et de fort abstrait. Nous avons rencontré de nombreux problèmes comme des incompatibilités, un manque de librairies ou encore un manque de mémoire et puissance processeur.
Nous avons pu voir que le modèle installé d’internet est beaucoup plus performant. Malgré tous les objets présents dans la pièce, il est capable de détecter une plaque alors que notre modèle entrainé dysfonctionne à de nombreuses reprises. On se rend compte de l’importance d’utiliser un grand nombre de photos et d’étapes pour être précis.
Pour améliorer ce système, il faudrait ajouter un capteur de présence en dessous de la barrière, utiliser une deuxième caméra pour le passage dans l’autre sens. Ensuite, ce serait de pouvoir créer l’algorithme de reconnaissance des lettres et chiffres qui n’a pas peut être réaliser dans le cadre de ce projet, et définir par la même occasion des heures d’arrivées et de départs d’une certaine plaque et ainsi pouvoir faire des statistiques.

24

## 7. Bibliographie :

https://pythonprogramming.net/testing-custom-object-detector-tensorflow-object-detection-api-tutorial/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
https://www.arduino.cc/en/Main/Software (Utilisé dans le cadre de plusieurs recherches de programmation propre à arduino)
https://www.locoduino.org/ (Celui-ci fût également beaucoup consulté)
Référence :
[1] Voir PDF micro servomoteur https://github.com/GPro97/Projet_gestion_camion/commit/3dcc848742897b9e47f678c52700cee1d 833aa73
[2] https://www.carnetdumaker.net/articles/controler-un-servomoteur-avec-une-carte-arduino-genuino/
[3] https://www.digikey.be/product-detail/en/arduino---bcmi-us-llc/A000066/1050-1024-ND/2784006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
[4] https://www.amazon.fr/1602A-Lignes-Caract%C3%A8re-Module-r%C3%A9tro-%C3%A9clairage/dp/B01EZQMKLQ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
[5] http://www.kapshop.com/p332/SpringRC-SM-S2309Small/product_info.html
[6] https://www.gotronic.fr/art-ajustable-horizontal-10k-8486-117.htm
[7] https://www.gotronic.fr/art-led-5mm-rouge-l51hd-2069.htm
[8] https://befr.rs-online.com/web/p/through-hole-fixed-resistors/0135500/
[9] https://befr.rs-online.com/web/p/processor-microcontroller-development-kits/1747510/
[10] https://befr.rs-online.com/web/p/video-modules/9132664/
[11] https://befr.rs-online.com/web/p/breadboard-jumper-wire-kits/7916463/?sra=pstk

25

[12] https://befr.rs-online.com/web/p/breadboard-jumper-wire-kits/7916454/
[13] https://www.amazon.fr/SODIAL-140pcs-essais-soudure-Arduino/dp/B00K67XXSI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

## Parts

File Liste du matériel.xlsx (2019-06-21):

Partie | Composants | Prix unit. | Qte | Prix tot. | Fournisseur | Réf site | Lien | Etat
Arduino | Arduino Uno | 20.75 € | 1 | 20.75 € | Digi-Key | A000066 | [3] | Fourni par l'école | https://www.digikey.be/product-detail/en/arduino---bcmi-us-llc/A000066/1050-1024-ND/2784006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
 | LCD | 7.57 € | 1 | 7.57 € | Amazon | DLM-B00XOYIXI0 | [4] | Fourni par l'école | https://www.amazon.fr/1602A-Lignes-Caract%C3%A8re-Module-r%C3%A9tro-%C3%A9clairage/dp/B01EZQMKLQ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
 | Servomoteur | 4.75 € | 1 | 4.75 € | KAPshop | / | [5] | Fourni par l'école | http://www.kapshop.com/p332/SpringRC-SM-S2309Small/product_info.html
 | Potentiomètre 10K | 0.25 € | 2 | 0.50 € | Gotronic | 04601 | [6] | Fourni par l'école | https://www.gotronic.fr/art-ajustable-horizontal-10k-8486-117.htm
 | Led rouge | 0.15 € | 2 | 0.30 € | Gotronic | 03030 | [7] | Fourni par l'école | https://www.gotronic.fr/art-led-5mm-rouge-l51hd-2069.htm
 | Résistance 220ohms Pack de 10 | 0.26 € | 1 | 0.26 € | RS Components | 135-500 | [8] | Fourni par l'école | https://befr.rs-online.com/web/p/through-hole-fixed-resistors/0135500/
 | Sous-total | 33.73 €
Raspberry | Raspberry Pi 3 B+ | 63.70 € | 1 | 63.70 € | RS Components | 174-7510 | [9] | Fourni par l'école | https://befr.rs-online.com/web/p/processor-microcontroller-development-kits/1747510/
 | Pi caméra V2 | 23.09 € | 1 |  | RS Components | 913-2664 | [10] | Fourni par l'école | https://befr.rs-online.com/web/p/video-modules/9132664/
 | Sous-total | 86.79 €
Communication | Câble mâle-mâle | 2.41 € | 1 | 2.41 € | RS Components | 791-6463 | [11] | Fourni par l'école | https://befr.rs-online.com/web/p/breadboard-jumper-wire-kits/7916463/?sra=pstk
 | Câble mâle-femelle | 2.41 € | 2 | 4.82 € | RS Components | 791-6454 | [12] | Fourni par l'école | https://befr.rs-online.com/web/p/breadboard-jumper-wire-kits/7916454/
 | Jumper Cable Kit Fil | 2.50 € | 1 | 2.50 € | Amazon | 14731 | [13] | Fourni par l'école | https://www.amazon.fr/SODIAL-140pcs-essais-soudure-Arduino/dp/B00K67XXSI
 | Sous-total | 7.32 €
Montage pratique | Bois | 20 € | / | / | Récupération | / | / | /
 | Impression 3D | ( €/g ) | ( m ) | ( g ) | Nombre d'essai | Prix total
 | Barrière | 0.035 | 0.8 | 6 | 2 | 0.420 € |  | Fourni par l'école
 | Support haut du servo | 0.035 | 0.49 | 3 | 1 | 0.105 € |  | Fourni par l'école
 | Support bas du servo | 0.035 | 1.2 | 8 | 1 | 0.280 € |  | Fourni par l'école
 | Sous-total |  |  |  |  | 0.81 €
 | Total général | 128.65 €

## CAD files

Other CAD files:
Modélisation 3D/Barrière.ipt
Modélisation 3D/Support bas servomoteur.ipt
Modélisation 3D/Support haut servomoteur.ipt

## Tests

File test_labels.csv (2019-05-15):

filename | width | height | class | xmin | ymin | xmax | ymax
img25.jpg | 4032 | 1960 | licenceplate | 1976 | 982 | 2174 | 1025
img10.jpg | 4032 | 1960 | licenceplate | 1359 | 1150 | 1656 | 1227
img10.jpg | 4032 | 1960 | licenceplate | 2250 | 991 | 2390 | 1037
img20.jpg | 4032 | 1960 | licenceplate | 1979 | 856 | 2183 | 904
img30.jpg | 4032 | 1960 | licenceplate | 718 | 1024 | 1030 | 1102
img30.jpg | 4032 | 1960 | licenceplate | 2991 | 830 | 3315 | 896
img5.jpg | 4032 | 1960 | licenceplate | 1152 | 1082 | 1361 | 1133
img15.jpg | 4032 | 1960 | licenceplate | 1500 | 1236 | 1776 | 1317

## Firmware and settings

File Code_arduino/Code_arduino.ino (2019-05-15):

//This library are used for the lcd screen and the servomotor
#include <Servo.h>
#include <LiquidCrystal.h>

#define LEDPIN 13

int action_barriere;

//Here, some pin numbers are assigned to a variable name
int pot_binaire = 0;
int com_raspberry = 2;
int led_rouge = 6;
int potentiometre = A0;

//we can control the servo motor with a single instruction, but the movement is too fast for the gate. In this program, we control the speed of the gate movement.
const int temps_barriere_entre_2degrees = 40;   //40 ms is the time between two movements of a 1 degree angle
const int temps_barriere_attente = 2000;        //When the gate is open, it waits 2 seconds (2000 ms) before going back down
int position_barriere = 89;                     //The value assigned to this variable changes when the gate is moving.

//The following variables are used in the gate movement program.
long temps_communication;
long t_actuel;
bool flag_barriere_montee = false;
bool flag_barriere_descente = false;
bool flag_barriere_attente = false;
bool flag_maintien_barriere = false;
bool flag_lcd_open = false;

//And these are used in the LED blink program.
bool etat_led = false;
long t_led_rouge = 0;
float tempo;


Servo servo_barriere;                           //The name of the servo motor is setting
LiquidCrystal lcd(7,8,9,10,11,12);              //Selection of the different pin number use for the lcd screen


void setup() {

  //Then we can assign each pin to input or output.
                                  //Reminder:
  pinMode(LEDPIN, OUTPUT);        //Pin 13
  pinMode(com_raspberry, INPUT);  //Pin 2
  pinMode(led_rouge, OUTPUT);     //Pin 6
  pinMode(potentiometre, INPUT);  //Pin A0

 
  servo_barriere.attach(3);       //The servomotor has to be attach to a pin. Here the pin 3
  servo_barriere.write(89);       //Because of the way the servomotor is put, we have to tilt the barrier to 89° so that it is horizontal
  lcd.begin(16,2);                //This is a configuration of the screen's size
  
  delay(2000);                    //When the setup is done, we wait 2 seconds. A lot of forums and website give this recommendation.
}


void barriere(void){
  
  if(!flag_lcd_open){
    lcd.setCursor(1,0);                           //The cursor position is initialized
    lcd.write("Bonjour, l'ami");                       //Then we write a word or a sentence on the screen
    lcd.setCursor(3,1);
    lcd.write("Bienvenue!");
    flag_lcd_open = true;                         //If we have just write on the lcd, we set this flag to don't pass here anymore before the next cycle
  }
  
  
  if(!flag_barriere_montee && !flag_barriere_attente && !flag_barriere_descente){ //We check if the gate is always horizontal
    if (millis() - t_actuel >= temps_barriere_entre_2degrees) {                   //We check if the elapsed time is equal or higher then the value of the variable name (=40 ms)
      position_barriere -- ;                      //If it's confirmed, we decrease the angle of the gate. The direction of the servomotor is reversed
      servo_barriere.write(position_barriere);    //The angle is write on the servomotor
      t_actuel = millis();                        //The elapsed time is updated
      if (position_barriere == 20){
        flag_barriere_montee = true;              //When the gate is at the top, the variable name is setting. In this way, we won't go into the loop anymore
        lcd.clear();
        lcd.setCursor(3,0);
        lcd.write("Passez une");
        lcd.setCursor(1,1);
        lcd.write("bonne journee");
      }
    }
  }

  if(flag_barriere_montee && !flag_barriere_attente && !flag_barriere_descente){  //We check if the gate is at the top
    if(action_barriere == HIGH){
      t_actuel = millis();
    }
    if(millis() - t_actuel >= temps_barriere_attente){                            //We check if the elapsed time is equal or higher then the value of the variable name (=2000 ms)
      flag_barriere_attente = true;               //The variable name is setting because we have waiting. In this way, we won't go into the loop anymore
    }
  }

  if(flag_barriere_montee && flag_barriere_attente && !flag_barriere_descente){   //We check if the gate is at the top and if we have waiting
    if (millis() - t_actuel >= temps_barriere_entre_2degrees) {                   //We check if the elapsed time is equal or higher then the value of the variable name (=40 ms)
      position_barriere ++ ;                      //We increase the angle of the gate
      servo_barriere.write(position_barriere);    //The angle is write on the servomotor
      t_actuel = millis();                        //The elapsed time is updated
      if (position_barriere == 89){
        flag_barriere_descente = true;            //When the gate is at the down, the variable name is setting
      }
    }
  }

  if(flag_barriere_montee && flag_barriere_attente && flag_barriere_descente){    //When the cycle is finished,
    flag_barriere_montee = false;                 //all of this variable name is reset
    flag_barriere_attente = false;
    flag_barriere_descente = false;
    flag_maintien_barriere = false;
    flag_lcd_open = false;
    lcd.clear();                                  //The lcd screen is cleared
    digitalWrite(led_rouge, LOW);                 //and the red LED is turned off
  }
}

void clignotement(float temps_clignotement){          //The input value is the time for the flashing frequency which was calculated before
  
  //In this part of the program, we will test the elapsed time with the time required for the frequency
  
  if(millis() - t_led_rouge >= temps_clignotement){  //"millis()" is the elapsed time of the arduino card
    t_led_rouge = millis();
    etat_led = digitalRead(led_rouge);
    if(etat_led == LOW){                             //To create a blink, we check the current state of the LED to turn it on or off
      digitalWrite(led_rouge, HIGH);
    }else{
      digitalWrite(led_rouge, LOW);
    }
  }
}

void loop() {
  digitalWrite(LEDPIN, HIGH);                     //When the program is looping, the small led is alight.

  pot_binaire = analogRead(potentiometre);        //The value of the analog potentiometer is recovered.
  float frequence = map(pot_binaire,0,1005,1,6);  //This instruction gives a value include between 1 and 6. It's the frequency of the red LED.
  tempo = (1/frequence) * 1000;                   //The frequency is converted to seconds.

  action_barriere = digitalRead(com_raspberry);   //The value of the input pin is read. This one comes from the raspberry card
  
  if (action_barriere == 0 && flag_maintien_barriere == LOW){
    temps_communication = millis();
  }
  
  

  //Here, we check two condition. Firstly, if the raspberry detect a number plate. And secondly, if the gate is closed. If only one is HIGH, the condition is confirm.
  if (action_barriere == HIGH | flag_maintien_barriere == HIGH){
    if (millis() - temps_communication >= 1000){
    flag_maintien_barriere = true;                //This flag authorise to pass if the gate is in movement. It will be reset at the end of the movement.
    clignotement(tempo);                          //And this one makes the red LED blink
    barriere();                                   //This instruction call the part of the program which move the gate.     
    }
  }
}

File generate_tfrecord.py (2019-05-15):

"""
Usage:
  # From tensorflow/models/
  # Create train data:
  python generate_tfrecord.py --csv_input=data/train_labels.csv  --output_path=train.record
  # Create test data:
  python generate_tfrecord.py --csv_input=data/test_labels.csv  --output_path=test.record
"""
from __future__ import division
from __future__ import print_function
from __future__ import absolute_import

import os
import io
import pandas as pd
import tensorflow as tf

from PIL import Image
from object_detection.utils import dataset_util
from collections import namedtuple, OrderedDict

flags = tf.app.flags
flags.DEFINE_string('csv_input', '', 'Path to the CSV input')
flags.DEFINE_string('output_path', '', 'Path to output TFRecord')
flags.DEFINE_string('image_dir', '', 'Path to images')
FLAGS = flags.FLAGS


# TO-DO replace this with label map
def class_text_to_int(row_label):
    if row_label == 'licenceplate':
        return 1
    else:
        None


def split(df, group):
    data = namedtuple('data', ['filename', 'object'])
    gb = df.groupby(group)
    return [data(filename, gb.get_group(x)) for filename, x in zip(gb.groups.keys(), gb.groups)]


def create_tf_example(group, path):
    with tf.gfile.GFile(os.path.join(path, '{}'.format(group.filename)), 'rb') as fid:
        encoded_jpg = fid.read()
    encoded_jpg_io = io.BytesIO(encoded_jpg)
    image = Image.open(encoded_jpg_io)
    width, height = image.size

    filename = group.filename.encode('utf8')
    image_format = b'jpg'
    xmins = []
    xmaxs = []
    ymins = []
    ymaxs = []
    classes_text = []
    classes = []

    for index, row in group.object.iterrows():
        xmins.append(row['xmin'] / width)
        xmaxs.append(row['xmax'] / width)
        ymins.append(row['ymin'] / height)
        ymaxs.append(row['ymax'] / height)
        classes_text.append(row['class'].encode('utf8'))
        classes.append(class_text_to_int(row['class']))

    tf_example = tf.train.Example(features=tf.train.Features(feature={
        'image/height': dataset_util.int64_feature(height),
        'image/width': dataset_util.int64_feature(width),
        'image/filename': dataset_util.bytes_feature(filename),
        'image/source_id': dataset_util.bytes_feature(filename),
        'image/encoded': dataset_util.bytes_feature(encoded_jpg),
        'image/format': dataset_util.bytes_feature(image_format),
        'image/object/bbox/xmin': dataset_util.float_list_feature(xmins),
        'image/object/bbox/xmax': dataset_util.float_list_feature(xmaxs),
        'image/object/bbox/ymin': dataset_util.float_list_feature(ymins),
        'image/object/bbox/ymax': dataset_util.float_list_feature(ymaxs),
        'image/object/class/text': dataset_util.bytes_list_feature(classes_text),
        'image/object/class/label': dataset_util.int64_list_feature(classes),
    }))
    return tf_example


def main(_):
    writer = tf.python_io.TFRecordWriter(FLAGS.output_path)
    path = os.path.join(FLAGS.image_dir)
    examples = pd.read_csv(FLAGS.csv_input)
    grouped = split(examples, 'filename')
    for group in grouped:
        tf_example = create_tf_example(group, path)
        writer.write(tf_example.SerializeToString())

    writer.close()
    output_path = os.path.join(os.getcwd(), FLAGS.output_path)
    print('Successfully created the TFRecords: {}'.format(output_path))


if __name__ == '__main__':
    tf.app.run()

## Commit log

2019-03-13 Code servo de 0 à 165 degree sans controle de vitesse
2019-03-13 Fonctionnement du servo avec BP
2019-03-17 Contrôle de vitesse du servo-moteur fonctionnant
2019-03-19 Fonctionnement du servo, du lcd et commande de la fréquence de la led par un potentiomètre
2019-04-02 Petite de la fréquence
    [Liste du matériel.xlsx]
2019-04-02 Revert "Petite de la fréquence"
    This reverts commit 3b395eb5abf3ee8b0de5c93c33b6e8f8dc4804a4.
    [Liste du matériel.xlsx]
2019-04-02 Revert "Revert "Petite de la fréquence""
    This reverts commit 89d178e250e2b4bfa76e7457b3aedce6b70a13c5.
    [Liste du matériel.xlsx]
2019-04-03 1er schéma de câblage de l'arduino
2019-04-03 Pdf du servo-moteur
2019-04-04 Pdf de présentation
2019-05-10 Ajout de quelques composants
    [Liste du matériel.xlsx]
2019-05-10 Ajout de commentaires - Non fini
2019-05-12 Code arduino complet et commenté
2019-05-14 Code arduino version final
2019-05-14 Logiciel qui utilise la picamera pour ainsi qu'un modèle pour faire de la reconnaissance d'objet.
2019-05-15 logiciel de transformation de xml à csv
2019-05-15 modification pour exucuter le programme dans la bonne directory
2019-05-15 programme de trensformation des fichiers .csv en .TFRecord
2019-05-15 changement du nom de la classe (ou des classes) à détecter
2019-05-15 fichier .csv obtenu avec le programme xml_to_csv
    [test_labels.csv, train_labels.csv]
2019-05-15 Modification du code arduino pour la communication avec le raspberry
2019-05-15 fichier de configuration du modèle
2019-05-15 modification du fichier de configuration du modèle
2019-05-15 modification du fichier de reconnaissance pour acceuillir le nouveau modèle.
2019-05-15 modification pour utiliser le modèle d'internet et modification pour active ou non un pin suivant si il y a détection de plaque
2019-05-15 Fichier .ipj et .ipt des modèles 3D
    [Barrière.ipt, Support bas servomoteur.ipt, Support haut servomoteur.ipt]
2019-05-16 Finalisation de la liste des composants
    [Liste du matériel.xlsx]
2019-05-16 Révisions d'un défaut dans la table de figure
2019-05-17 Final report_Reconnaissance de plaque d'immatriculation
2019-05-20 Final video_Reconnaissance de plaque d'immatriculation
2019-05-20 Final presentation_Reconnaissance de plaque d'immatriculation
2019-06-21 Add files via upload
    Modification du fichier excel pour la présentation sur le rapport
    [Liste du matériel.xlsx]
2019-06-21 report_Reconnaissance de plaque d'immatriculation_corrected
